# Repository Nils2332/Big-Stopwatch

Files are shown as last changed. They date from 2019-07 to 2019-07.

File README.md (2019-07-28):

# Big-3D-Printed-Stopwatch

A simple 4 digit stopwatch triggered by 2 remote Buttons

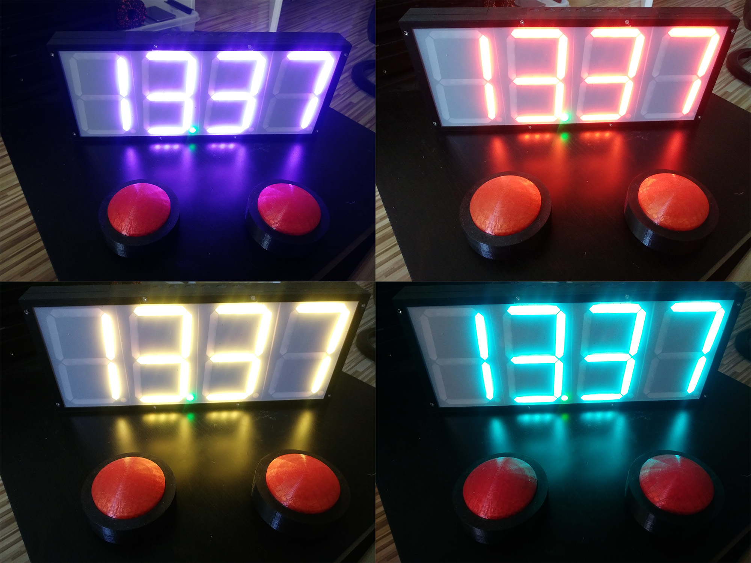
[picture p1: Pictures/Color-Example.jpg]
Overview

Overview
Main Body
Exploded Animation of the Main-Body
Animation Demo<br />
Demo of the running anmimation and rainbow highscore sign
## Built With
Counter powered by an ESP32 for future Extension with an Bluetooth App and more Functionalety.<br />
Programmeble WS2812 LEDs<br />
Remote Buttons: Custom PCB powered by an STM32F103<br />
Radio: nRF905 on 868 MHz band<br />

## License

This project is licensed under the MIT License

## Acknowledgments
* Inspiration @Jankae

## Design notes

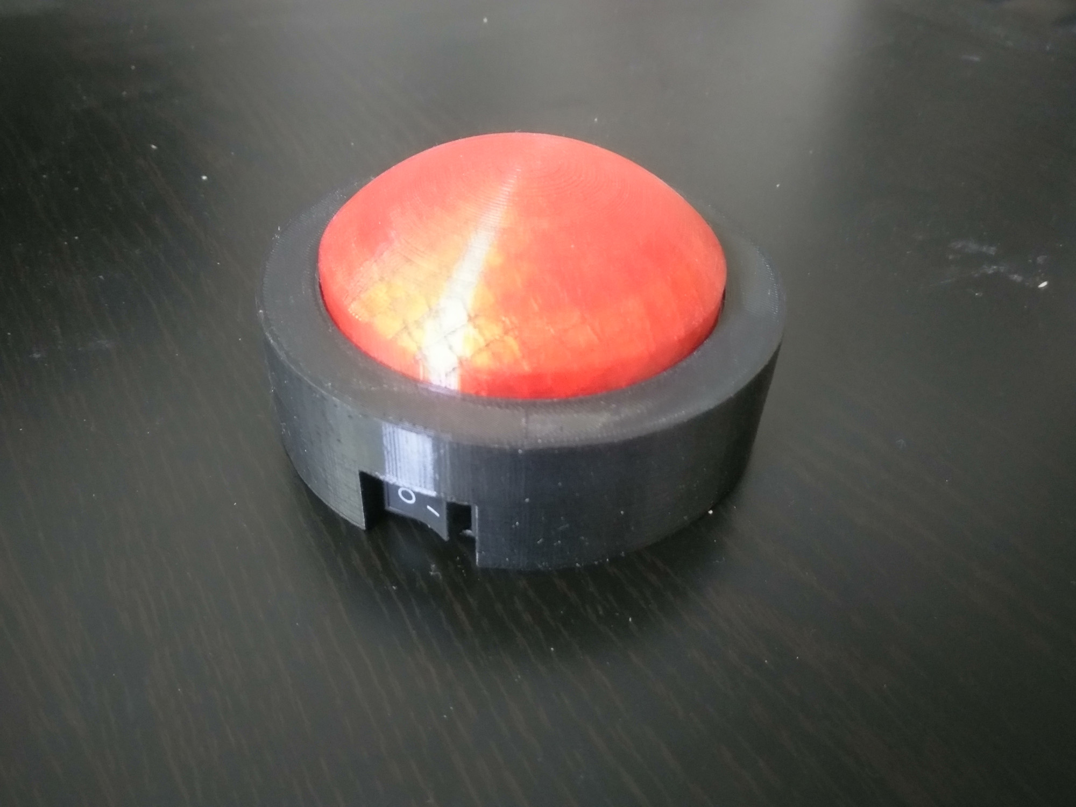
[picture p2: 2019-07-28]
Pictures/Button.jpg

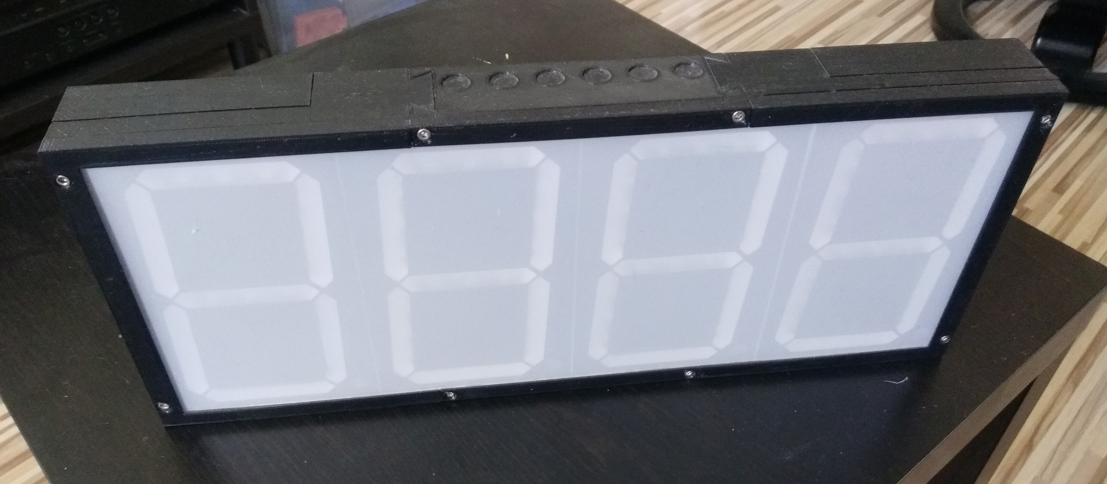
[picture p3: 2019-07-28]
Pictures/Main-Case.jpg

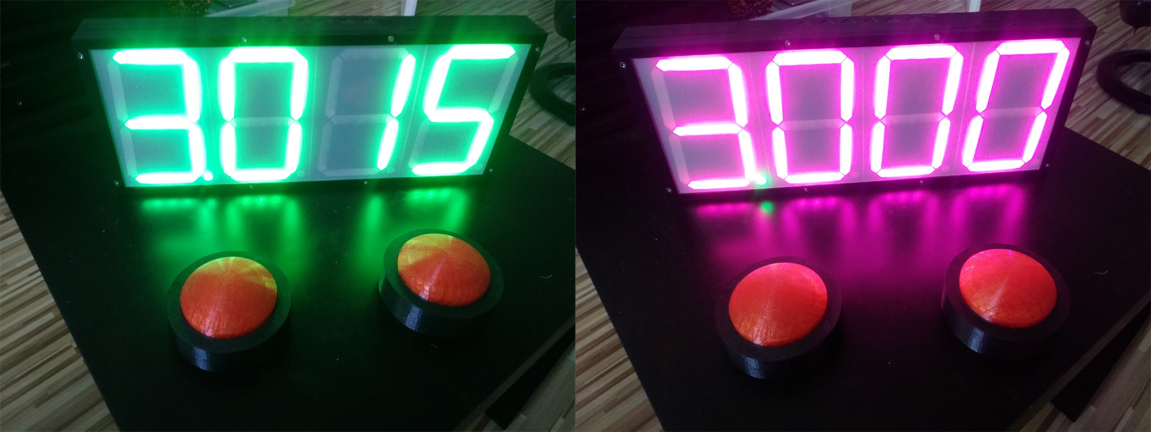
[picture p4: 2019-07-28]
Pictures/Button-Voltage.jpg

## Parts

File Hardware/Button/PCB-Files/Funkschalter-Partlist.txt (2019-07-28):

Partlist

Exported from Funkschalter1V0.1.sch at 01.06.2018 23:58

EAGLE Version 9.0.0 Copyright (c) 1988-2018 Autodesk, Inc.

Assembly variant: 

Part     Value             Device            Package     Library     Sheet

BAT1+    TPTP20R           TPTP20R           TP20R       testpad     1
BAT1-    TPTP20R           TPTP20R           TP20R       testpad     1
BAT2+    TPTP20R           TPTP20R           TP20R       testpad     1
BAT2-    TPTP20R           TPTP20R           TP20R       testpad     1
C1       0.1uF             C-EUC0603         C0603       rcl         1
C2       0.1uF             C-EUC0603         C0603       rcl         1
C3       10nF              C-EUC0603         C0603       rcl         1
C4       4,7uF             C-EUC0603         C0603       rcl         1
C6       4,7uF             C-EUC0603         C0603       rcl         1
C19      10nF              C-EUC0603         C0603       rcl         1
C20      4.7uF             C-EUC0603         C0603       rcl         1
C21      22pF              C-EUC0603         C0603       rcl         1
C22      22pF              C-EUC0603         C0603       rcl         1
C23      33pF              C-EUC0603         C0603       rcl         1
C24      3.3nF             C-EUC0603         C0603       rcl         1
C25      33pF              C-EUC0603         C0603       rcl         1
C26      33pF              C-EUC0603         C0603       rcl         1
C27      10nF              C-EUC0603         C0603       rcl         1
C28      33pF              C-EUC0603         C0603       rcl         1
C29      5.6pF             C-EUC0603         C0603       rcl         1
C30      4.7pF             C-EUC0603         C0603       rcl         1
C31      3.9pF             C-EUC0603         C0603       rcl         1
IC1      nRF905            NRF905QFN32_5X5MM QFN32-5X5MM nordic-semi 1
Q1       X322516MRB4SI     XTAL-4-3225       NX3225      adafruit    1
R1       10k               R-EU_R0603        R0603       rcl         1
R2       1M                R-EU_R0603        R0603       rcl         1
R3       22k               R-EU_R0603        R0603       rcl         1
R4       10k               R-EU_R0603        R0603       rcl         1
R5       0                 R-EU_R0603        R0603       rcl         1
R6       20k               R-EU_R0603        R0603       rcl         1
R7       100k              R-EU_R0603        R0603       rcl         1
R8       200k              R-EU_R0603        R0603       rcl         1
R9       18k               R-EU_R0603        R0603       rcl         1
R10      0                 R-EU_R0603        R0603       rcl         1
ST-LINK  B5B-ZR            B5B-ZR            B5B-ZR      jst         1
SW1      K2-6639SP-C4SC-04 SPST_TACT-EVQQ2   EVQ-Q2      adafruit    1
SW2      TS                SPST_TACT-EVQQ2   EVQ-Q2      adafruit    1
SW3      TS                SPST_TACT-EVQQ2   EVQ-Q2      adafruit    1
SW4      TS                SPST_TACT-EVQQ2   EVQ-Q2      adafruit    1
SW5      TS                SPST_TACT-EVQQ2   EVQ-Q2      adafruit    1
SW6      TS                SPST_TACT-EVQQ2   EVQ-Q2      adafruit    1
SW7      TS                SPST_TACT-EVQQ2   EVQ-Q2      adafruit    1
SW8      TS                SPST_TACT-EVQQ2   EVQ-Q2      adafruit    1
SW9      SPST_TACT-EVQQ2   SPST_TACT-EVQQ2   EVQ-Q2      adafruit    1
U$1      STM32F030F4       STM32F030F4       TSSOP20     stm32f030f4 1
UART     B4B-ZR            B4B-ZR            B4B-ZR      jst         1

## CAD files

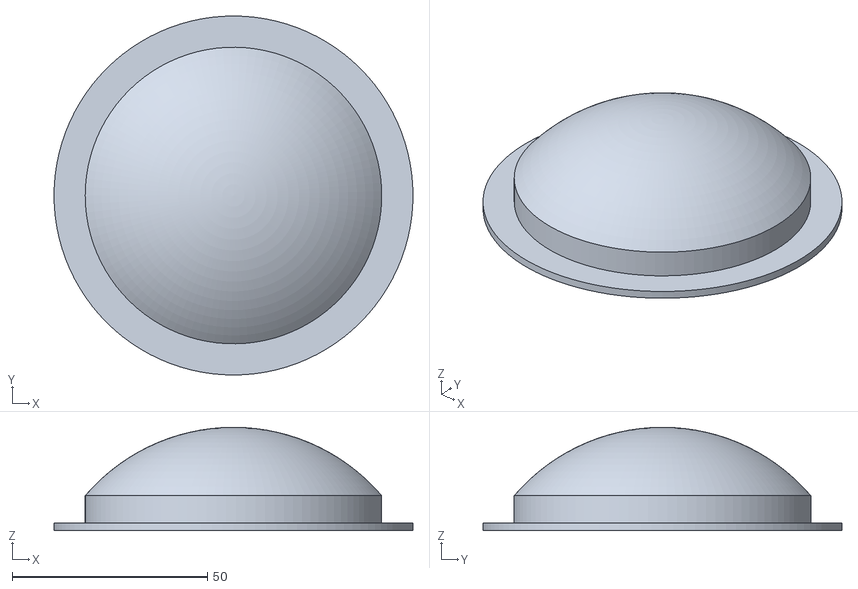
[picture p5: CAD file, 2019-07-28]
Hardware/Button/CAD-files/Bauteil2.stl
92.0 x 92.0 x 26.5

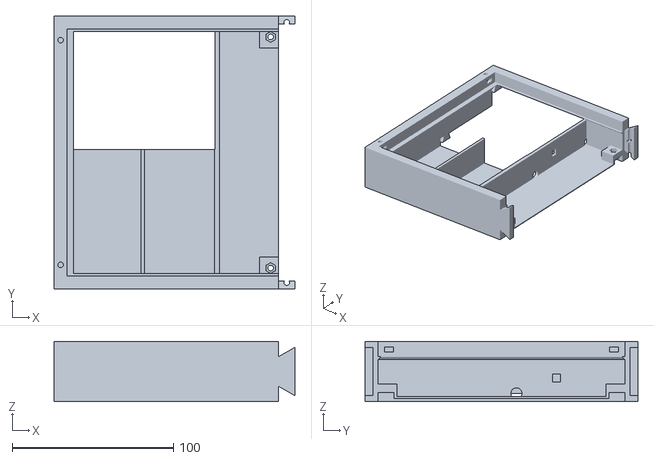
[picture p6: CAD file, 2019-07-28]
Hardware/Counter/CAD-files/Case_side_back.stl
149.4 x 169.5 x 37.3

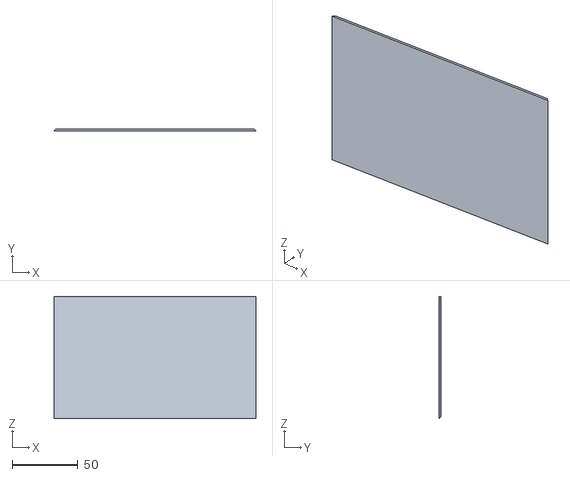
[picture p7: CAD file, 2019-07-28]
Hardware/Counter/CAD-files/Print/Zwischenplatt.stl
153.5 x 1.50 x 93.0

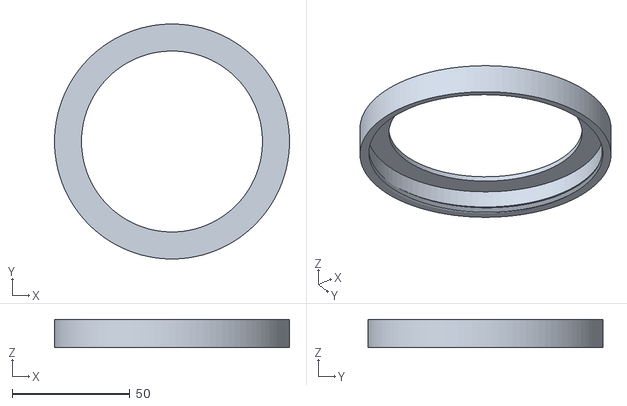
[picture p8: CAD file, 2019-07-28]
Hardware/Button/CAD-files/Bauteil5.stl
100.0 x 100.0 x 12.0

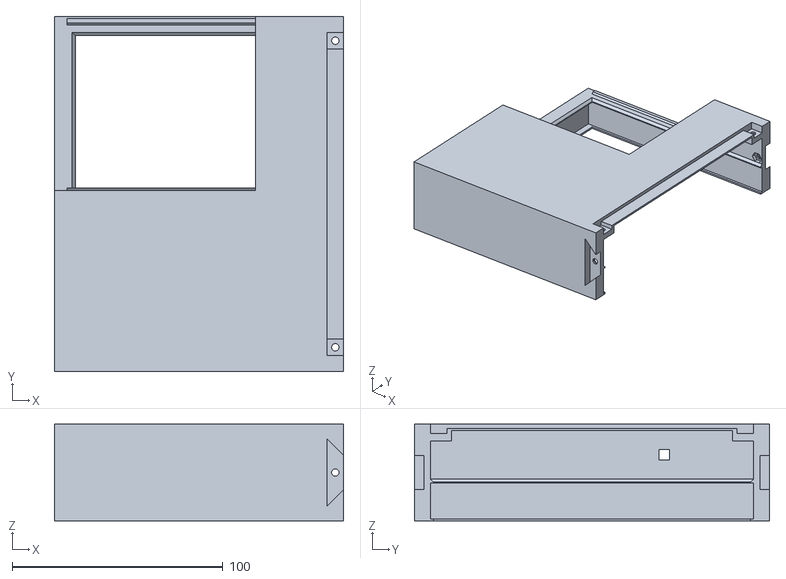
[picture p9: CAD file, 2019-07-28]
Hardware/Counter/CAD-files/Bauteil1_MIR.stl
137.4 x 168.5 x 46.0

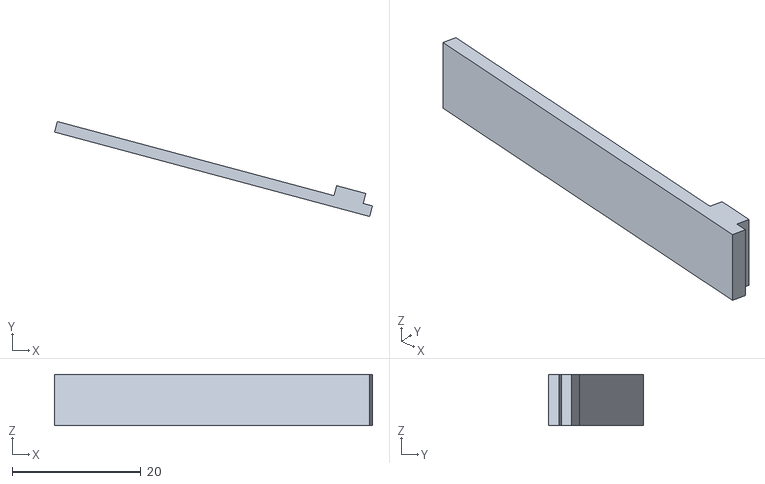
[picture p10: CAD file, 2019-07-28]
Hardware/Button/CAD-files/Spring.stl
49.4 x 14.8 x 8.00

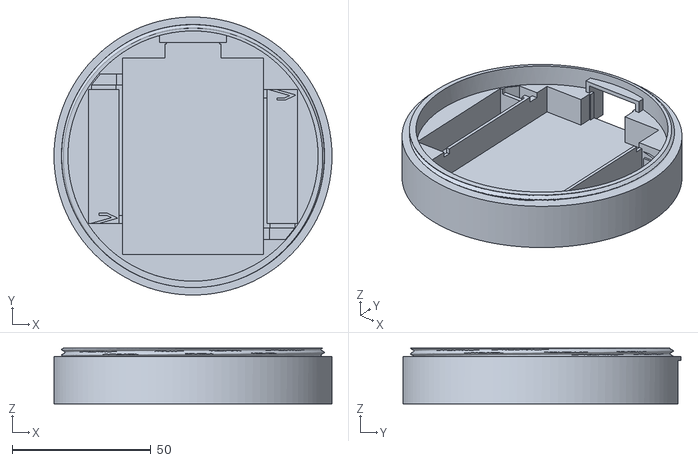
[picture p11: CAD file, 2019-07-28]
Hardware/Button/CAD-files/Bauteil6.stl
100.0 x 100.0 x 20.0

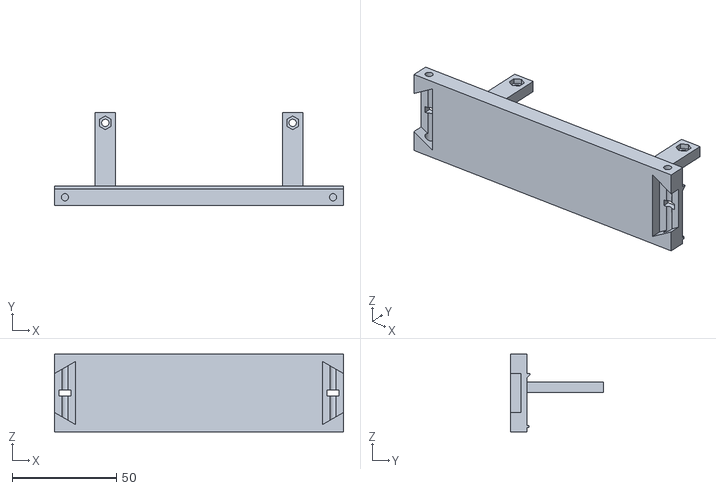
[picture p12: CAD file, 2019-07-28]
Hardware/Counter/CAD-files/Case_bottom_back.stl
138.8 x 44.7 x 37.3

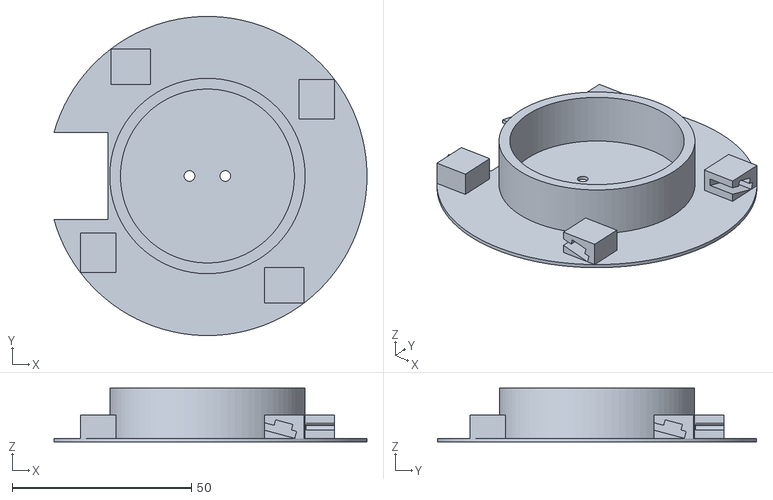
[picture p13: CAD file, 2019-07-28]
Hardware/Button/CAD-files/Bauteil1.stl
87.3 x 89.0 x 15.0

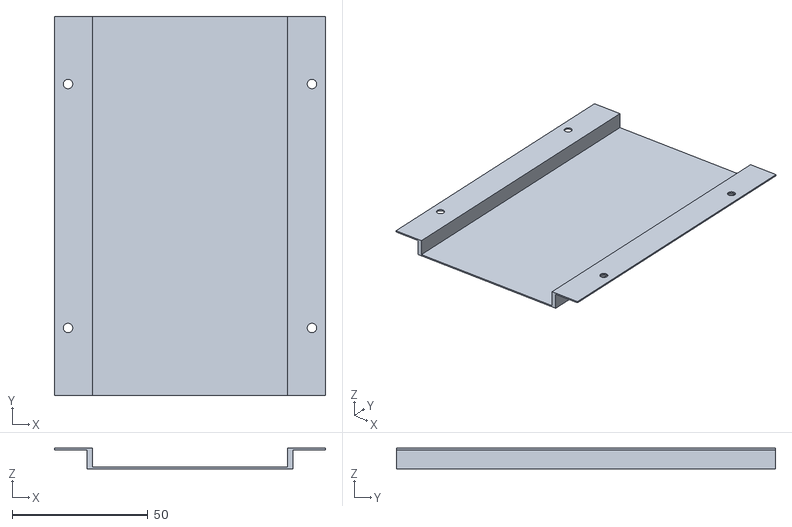
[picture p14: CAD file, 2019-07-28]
Hardware/Counter/CAD-files/PCB-Mount.stl
100.0 x 140.0 x 7.60

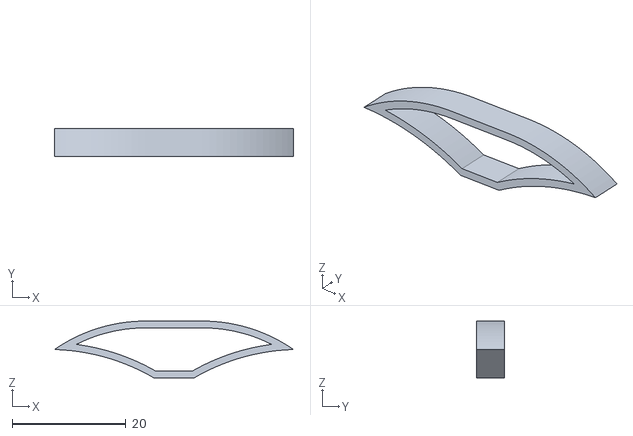
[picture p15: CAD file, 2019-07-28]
Hardware/Button/CAD-files/Spring2.stl
42.0 x 5.00 x 10.0

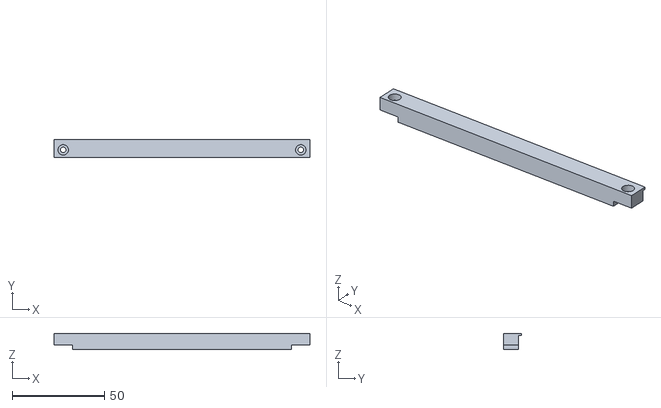
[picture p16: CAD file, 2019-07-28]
Hardware/Counter/CAD-files/Case_bottom_front.stl
138.8 x 9.50 x 8.90

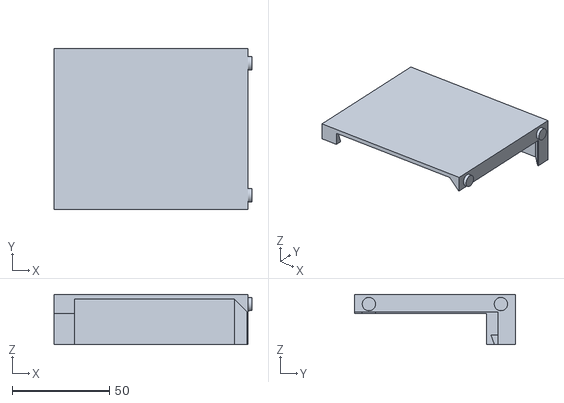
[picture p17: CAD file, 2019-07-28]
Hardware/Counter/CAD-files/Batcap3_MIR.stl
102.0 x 82.9 x 25.9

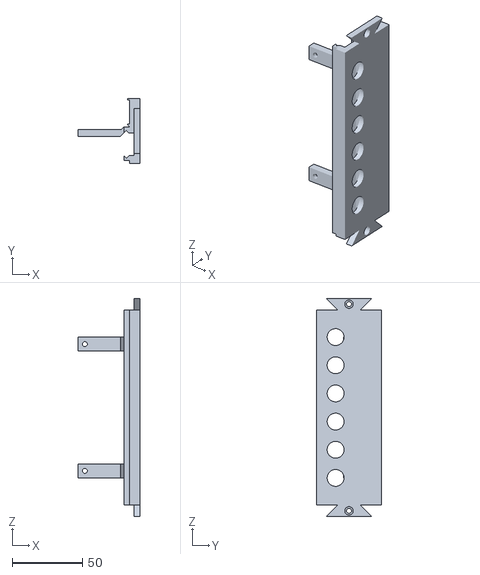
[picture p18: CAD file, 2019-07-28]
Hardware/Counter/CAD-files/TopFrame.stl
44.2 x 46.0 x 154.8

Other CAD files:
Hardware/Counter/CAD-files/Case_side_back_MIR1.stl
Hardware/Counter/CAD-files/Batcap3.stl
Hardware/Counter/CAD-files/Bauteil1.stl
Hardware/Counter/CAD-files/Cover_V2.stl
Hardware/Button/CAD-files/Bauteil1.ipt
Hardware/Button/CAD-files/Bauteil2.ipt
Hardware/Button/CAD-files/Bauteil5.ipt
Hardware/Button/CAD-files/Bauteil6.ipt
Hardware/Button/CAD-files/Button.iam
Hardware/Button/CAD-files/OldVersions/Bauteil1.0010.ipt
Hardware/Button/CAD-files/OldVersions/Bauteil2.0001.ipt
Hardware/Button/CAD-files/OldVersions/Bauteil5.0001.ipt
Hardware/Button/CAD-files/OldVersions/Bauteil6.0009.ipt
Hardware/Button/CAD-files/OldVersions/Button.0009.iam
Hardware/Button/CAD-files/OldVersions/Spring.0003.ipt
Hardware/Button/CAD-files/OldVersions/Spring2.0001.ipt
Hardware/Button/CAD-files/Spring.ipt
Hardware/Button/CAD-files/Spring2.ipt
Hardware/Counter/CAD-files/Backplate-housing.ipt
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

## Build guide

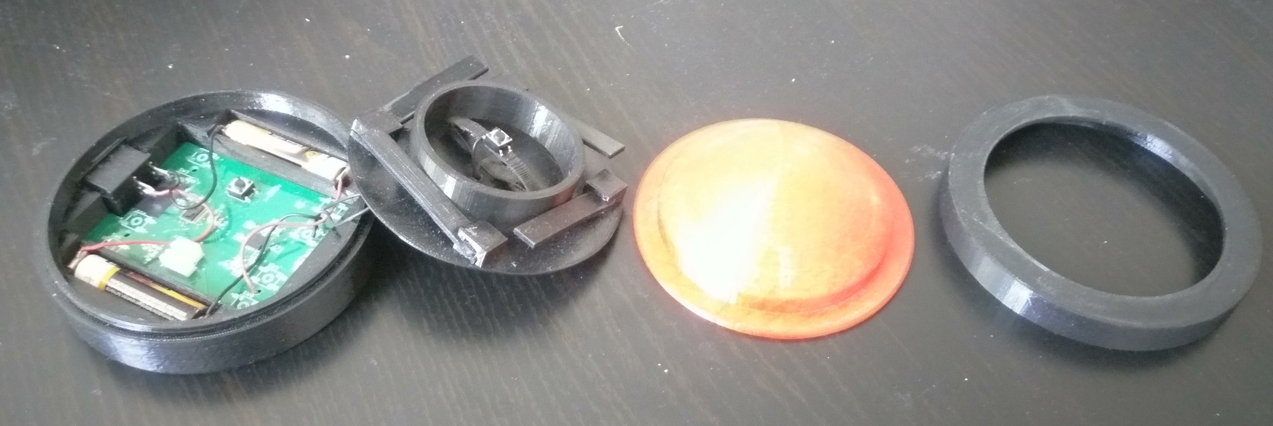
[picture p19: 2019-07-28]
Pictures/Button-disassembled.jpg

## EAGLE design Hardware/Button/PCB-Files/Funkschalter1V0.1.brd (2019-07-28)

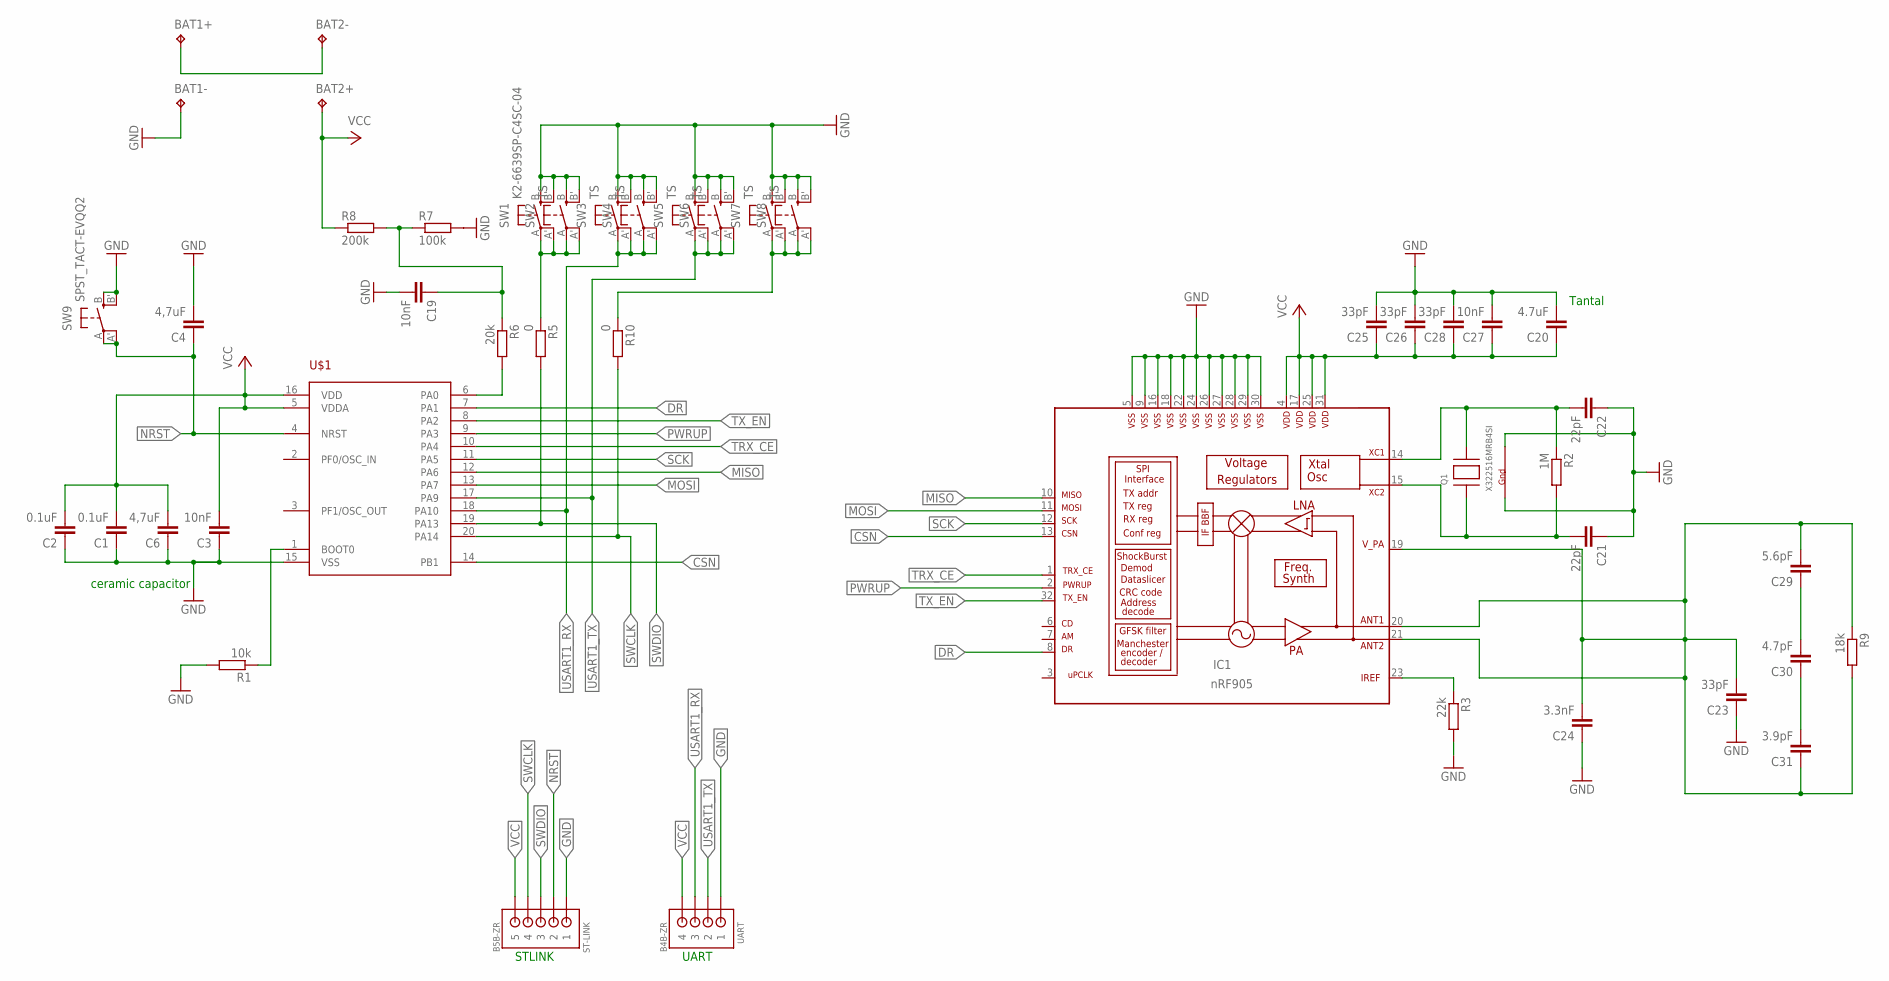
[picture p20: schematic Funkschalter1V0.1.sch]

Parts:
BAT1+, BAT1-, BAT2+, BAT2-: TPTP20R; TP20R
C1, C2: 0.1uF; C0603
C3, C19, C27: 10nF; C0603
C4, C6: 4,7uF; C0603
C20: 4.7uF; C0603
C21, C22: 22pF; C0603
C23, C25, C26, C28: 33pF; C0603
C24: 3.3nF; C0603
C29: 5.6pF; C0603
C30: 4.7pF; C0603
C31: 3.9pF; C0603
IC1: nRF905; QFN32-5X5MM
Q1: X322516MRB4SI; NX3225
R1: 10k; R0603
R2: 1M; R0603
R3: 22k; R0603
R5, R10: 0; R0603
R6: 20k; R0603
R7: 100k; R0603
R8: 200k; R0603
R9: 18k; R0603
ST-LINK: B5B-ZR
SW1: K2-6639SP-C4SC-04; EVQ-Q2
SW2, SW3, SW4, SW5, SW6, SW7, SW8: TS; EVQ-Q2
SW9: SPST_TACT-EVQQ2; EVQ-Q2
U$1: STM32F030F4; TSSOP20
UART: B4B-ZR

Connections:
CSN: IC1.13 (CSN), U$1.14 (PB1)
DR: IC1.8 (DR), U$1.7 (PA1)
GND: BAT1-.TP, C1.1, C2.1, C3.1, C4.2, C6.1, C19.2, C20.2, C21.1, C22.1, C23.1, C24.1, C25.2, C26.2, C27.2, C28.2, IC1.5 (VSS5), IC1.9 (VSS9), IC1.16 (VSS16), IC1.18 (VSS18), IC1.22 (VSS22), IC1.24 (VSS24), IC1.26 (VSS26), IC1.27 (VSS27), IC1.28 (VSS28), IC1.29 (VSS29), IC1.30 (VSS30), Q1.2 (G2), Q1.4 (G1), R1.2, R3.2, R7.2, ST-LINK.1, SW1.B (S), SW1.B' (S1), SW2.B (S), SW2.B' (S1), SW3.B (S), SW3.B' (S1), SW4.B (S), SW4.B' (S1), SW5.B (S), SW5.B' (S1), SW6.B (S), SW6.B' (S1), SW7.B (S), SW7.B' (S1), SW8.B (S), SW8.B' (S1), SW9.B (S), SW9.B' (S1), U$1.15 (VSS), UART.1
MISO: IC1.10 (MISO), U$1.12 (PA6)
MOSI: IC1.11 (MOSI), U$1.13 (PA7)
unnamed: R5.1, SW1.A, SW1.A' (P1), SW2.A, SW2.A' (P1)
unnamed: R1.1, U$1.1 (BOOT0)
unnamed: R6.2, U$1.6 (PA0)
unnamed: R10.1, SW7.A, SW7.A' (P1), SW8.A, SW8.A' (P1)
unnamed: BAT1+.TP, BAT2-.TP
unnamed: C19.1, R6.1, R7.1, R8.2
unnamed: C21.2, IC1.15 (XC2), Q1.1 (X1), R2.2
unnamed: C22.2, IC1.14 (XC1), Q1.3 (X2), R2.1
unnamed: IC1.23 (IREF), R3.1
unnamed: C23.2, C24.2, C29.2, C31.1, IC1.19 (VDD_PA), IC1.20 (ANT1), IC1.21 (ANT2), R9.1, R9.2
unnamed: C30.1, C31.2
unnamed: C29.1, C30.2
NRST: C4.1, ST-LINK.2, SW9.A, SW9.A' (P1), U$1.4 (NRST)
PWRUP: IC1.2 (PWR_UP), U$1.9 (PA3)
SCK: IC1.12 (SCK), U$1.11 (PA5)
SWCLK: R10.2, ST-LINK.4, U$1.20 (PA14)
SWDIO: R5.2, ST-LINK.3, U$1.19 (PA13)
TRX_CE: IC1.1 (TRX_CE), U$1.10 (PA4)
TX_EN: IC1.32 (TX_EN), U$1.8 (PA2)
USART1_RX: SW3.A, SW3.A' (P1), SW4.A, SW4.A' (P1), U$1.18 (PA10), UART.3
USART1_TX: SW5.A, SW5.A' (P1), SW6.A, SW6.A' (P1), U$1.17 (PA9), UART.2
VCC: BAT2+.TP, C1.2, C2.2, C3.2, C6.2, C20.1, C25.1, C26.1, C27.1, C28.1, IC1.4 (VDD4), IC1.17 (VDD17), IC1.25 (VDD25), IC1.31 (DVDD1V2), R8.1, ST-LINK.5, U$1.5 (VDDA), U$1.16 (VDD), UART.4

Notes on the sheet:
ceramic capacitor
Tantal
UART
STLINK

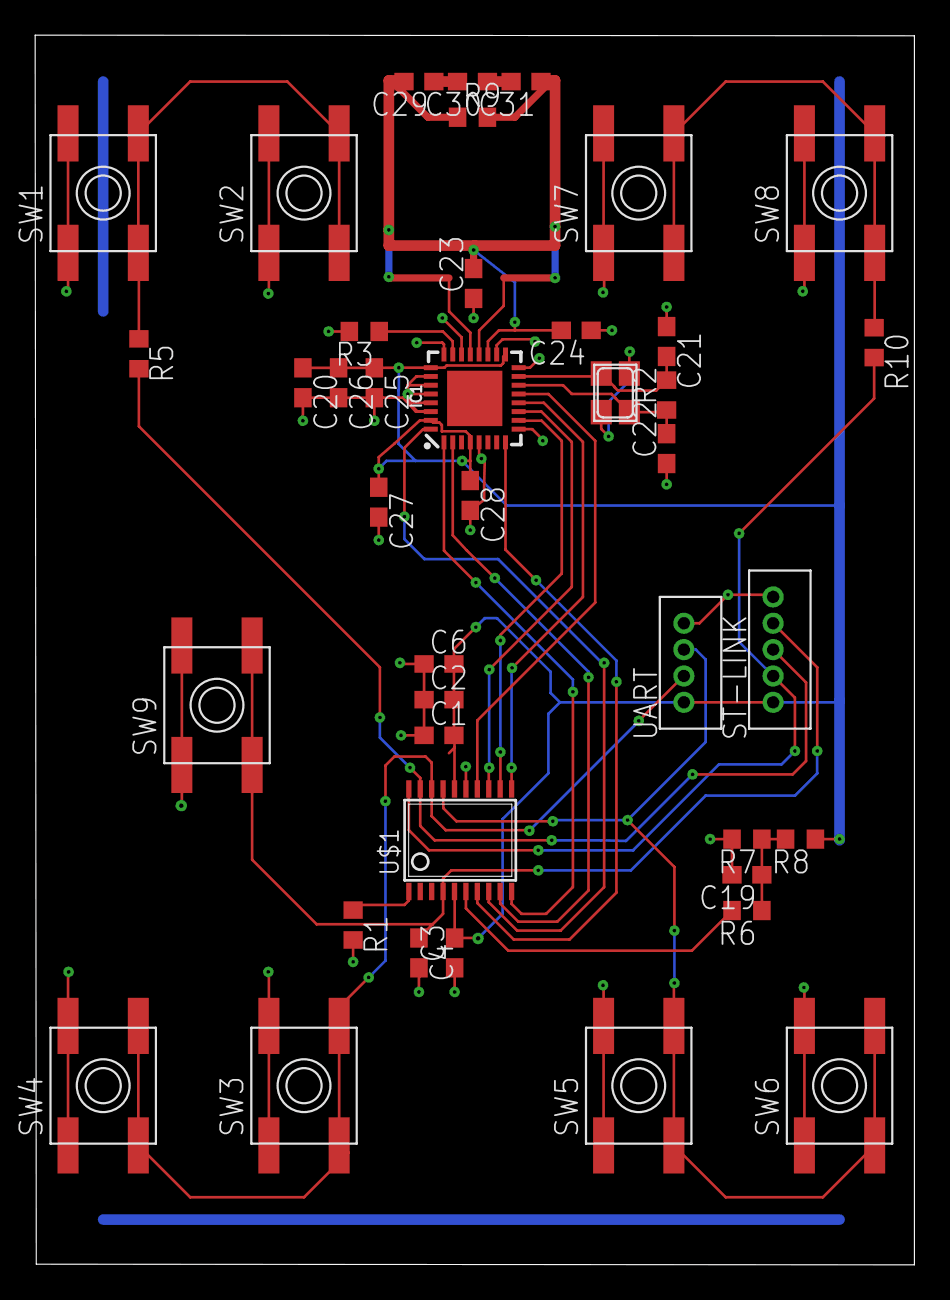
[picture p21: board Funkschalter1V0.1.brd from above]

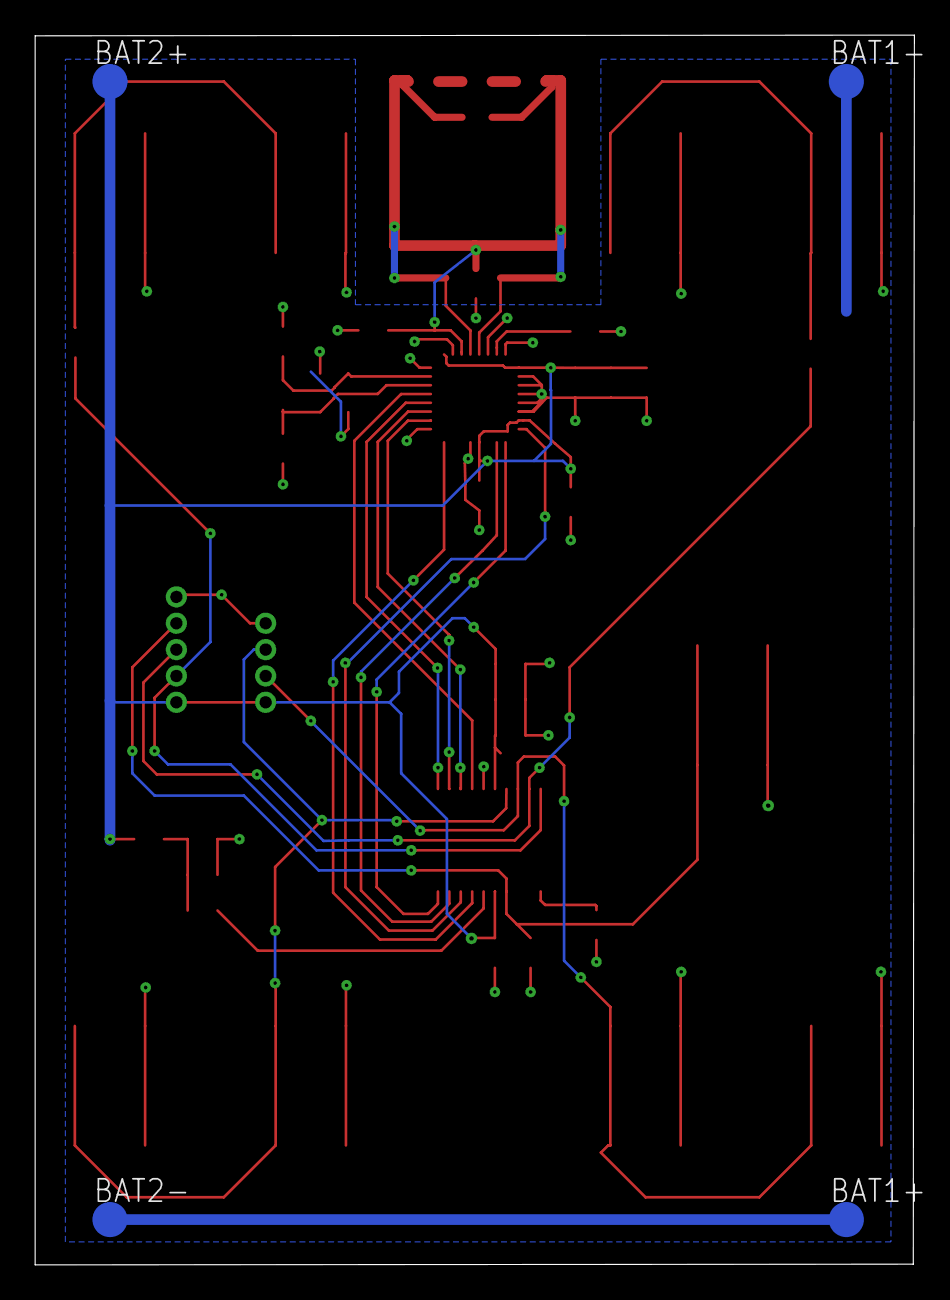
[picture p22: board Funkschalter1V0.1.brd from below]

Board: 2 copper layers, 50.0 x 70.0 mm, 45 parts (4 on the bottom side), 27 nets.

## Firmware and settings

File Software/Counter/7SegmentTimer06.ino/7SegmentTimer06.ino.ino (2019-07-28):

//Nils Schröder
//28.09.2018

#include <math.h>
#include <stdlib.h>
#include "nRF905\src\nRF905.h"
#include "LCD.h"
#include "modes.h"
#include "Debug.h"


#define T6 33
#define T5 25
#define T4 26
#define T3 27
#define T2 34
#define T1 35


#define RXADDR	0xABBAFFE0
#define TX1ADDR	0xABBAFFE1
#define TX2ADDR	0xABBAFFE2


#define Batpin1	4
#define Batpin2	2


uint8_t button[6] = { 0 };
uint8_t buttons = 0;
uint8_t button_used = 0;


double V_Bat1, V_Bat2;
double V_Button[2];

uint8_t V_Batlow = 0;
uint32_t oldtime_V = 0;

uint8_t remotereset = 0;
uint32_t remotedelay[2];
uint32_t remotecounter = 0;


LEDLCD LCD1(0);

float stattime;
float oldtime;
float record = 0;
uint8_t recordset = 0;

uint8_t remotebutton = 0;

uint8_t v_buttonshow = 0;

hw_timer_t * timer1 = NULL;
hw_timer_t * timer2 = NULL;
hw_timer_t * timer3 = NULL;

uint32_t oldtime_l = 0;
uint32_t sleepcounter = 0;
uint8_t sleeping = 0;

//timer1
void IRAM_ATTR getButtons()
{
	button[0] = !digitalRead(T1);
	button[1] = !digitalRead(T2);
	button[2] = !digitalRead(T3);
	button[3] = !digitalRead(T4);
	button[4] = !digitalRead(T5);
	button[5] = !digitalRead(T6);

	buttons = button[5] * 32 + button[4] * 16 + button[3] * 8 + button[2] * 4 + button[1] * 2 + button[0];

	button_used = 0;
	//Serial.println(buttons);
}


uint8_t oldpacket[2] = {};
//timer2
void IRAM_ATTR getRadio()
{

	remotecounter++;

	if (remotecounter > 350)
		remotereset = 0;
	//timerAlarmDisable(timer1);
	//timerAlarmDisable(timer2);
	//timerAlarmDisable(timer3);

	if (digitalRead(17))
	{
		Serial.print("Get Wireless: ");
		uint8_t buffer[NRF905_MAX_PAYLOAD];
		nRF905_read(buffer, sizeof(buffer));

		uint8_t id;
		uint8_t command;
		uint16_t timer;

		uint8_t packet;
		

		if (buffer[0] == 130)
		{
			id = buffer[1];
			command = buffer[2];
			packet = buffer[5];

			Serial.print(id);
			Serial.print("\t Packet: "), Serial.print(packet);
			//Voltage
			if (command == 1)
			{
				Serial.print("Voltage: ");
				V_Button[id - 1] = ((uint16_t)(buffer[3] << 8) | (buffer[4]));
				V_Button[id - 1] = V_Button[id - 1] / 1000;

				v_buttonshow = id;

				
				Serial.print("\t V: "), Serial.print(V_Button[id - 1]);

				oldpacket[id - 1] = packet;
			}
			//Button Pressed
			if (command == 2)
			{
				if (packet != oldpacket[id - 1])
				{

					timer = ((uint16_t)(buffer[3] << 8) | (buffer[4]));
					Serial.print("\t Delay: ");
					Serial.print(timer);
					remotedelay[id - 1] = timer;
					remotebutton = 1 << (id - 1);
					//Serial.println(buttons);
					button_used = 0;

					if (id == 1)
					{
						remotecounter = 0;
						remotereset++;
						Serial.print("\t Res#: "), Serial.print(remotereset);
					}

					oldpacket[id - 1] = packet;
				}
			}

			//ACK Packet
			//uint8_t compare[NRF905_MAX_PAYLOAD] = { 65, 67, 75, 0 };
			uint8_t compare[NRF905_MAX_PAYLOAD] = { 0 };
			compare[0] = 65;
			compare[1] = 67;
			compare[2] = 75;
			
			//for (uint8_t i = 0; i < NRF905_MAX_PAYLOAD; i++)
			//	Serial.print(compare[i]);

			//Serial.println(" ");

			if (id == 1)
			{
				Serial.println("\t Sending ACK");
				//Serial.println(id);
				while (!nRF905_TX(TX1ADDR, compare, sizeof(buffer), NRF905_NEXTMODE_RX));
			}

			if (id == 2)
			{
				Serial.println("\t Sending ACK");
				//Serial.println(id);
				while (!nRF905_TX(TX2ADDR, compare, sizeof(buffer), NRF905_NEXTMODE_RX));
			}
		}
	}

	//timerAlarmEnable(timer1);
	//timerAlarmEnable(timer2);
	//timerAlarmEnable(timer3);
}

//timer3
void IRAM_ATTR updateDisplay()
{
	//timerAlarmDisable(timer1);
	//timerAlarmDisable(timer2);
	//timerAlarmDisable(timer3);

	

	//timerAlarmEnable(timer1);
	//timerAlarmEnable(timer2);
	//timerAlarmEnable(timer3);
}

void setup()
{
	analogSetAttenuation(ADC_6db);

	//init Serial
	Serial.begin(115200);

	//configure Buttons
	pinMode(T1, INPUT);
	pinMode(T2, INPUT);
	pinMode(T3, INPUT);
	pinMode(T4, INPUT);
	pinMode(T5, INPUT);
	pinMode(T6, INPUT);

	digitalWrite(T1, HIGH);
	digitalWrite(T2, HIGH);
	digitalWrite(T3, HIGH);
	digitalWrite(T4, HIGH);
	digitalWrite(T5, HIGH);
	digitalWrite(T6, HIGH);
	//end Buttons

	//radio Avaiable PIN
	pinMode(17, INPUT);

	// Start up radio
	nRF905_init();

	// Set address of this device
	nRF905_setListenAddress(RXADDR);

	// Put into receive mode
	nRF905_RX();
	nRF905_powerUp();
	nRF905_RX();


	LCD1.init();

	//Timer init
	//esp_task_wdt_fee

	timer1 = timerBegin(1, 80, true);
	timerAttachInterrupt(timer1, &getButtons, true);
	timerAlarmWrite(timer1, 5000, true);
	timerAlarmEnable(timer1);

	timer2 = timerBegin(2, 80, true);
	timerAttachInterrupt(timer2, &getRadio, true);
	timerAlarmWrite(timer2, 5000, true);
	timerAlarmEnable(timer2);

	timer3 = timerBegin(0, 80, true);
	timerAttachInterrupt(timer3, &updateDisplay, true);
	timerAlarmWrite(timer3, 10000, true);
	timerAlarmEnable(timer3);

	//End timer


	Serial.println("7-Segment-Counter-Start");

	LCD1.setcolorhsv(0, 240, 1, 1);
	LCD1.setcolorhsv(1, 120, 1, 1);

	LCD1.clearALL();

	uint8_t samples = 10;
	V_Bat1 = 0, V_Bat2 = 0;
	for (uint8_t i = 0; i < samples; i++)
	{
		V_Bat1 = V_Bat1 + analogRead(Batpin1);
		V_Bat2 = V_Bat2 + analogRead(Batpin2);
	}

	V_Bat1 = V_Bat1 / samples;
	V_Bat2 = V_Bat2 / samples;

	Serial.print("V1: \t");
	Serial.println(V_Bat1);
	Serial.print("V2: \t");
	Serial.println(V_Bat2);

	V_Bat1 = V_Bat1 * 0.0016414;
	V_Bat2 = V_Bat2 * 0.0027313 - V_Bat1;

	LCD1.show(V_Bat1);
	update();
	delay(2000);
	LCD1.show(V_Bat2);
	update();
	//delay(2000);

}

float starttime;
float time;

void v_showbutton()
{
	cHSV oldcolor;
	oldcolor = LCD1.hsv[0];
	if (v_buttonshow == 1)LCD1.setcolorhsv(0, 110, 1, 1);
	if (v_buttonshow == 2)LCD1.setcolorhsv(0, 350, 1, 1);
	LCD1.show(V_Button[v_buttonshow - 1]);
	update();
	delay(2000);
	LCD1.clearALL();
	update();
	LCD1.setcolorhsv(0, oldcolor.H, oldcolor.S, oldcolor.V);
	v_buttonshow = 0;
}

void update()
{
	timerAlarmDisable(timer1);
	timerAlarmDisable(timer2);
	timerAlarmDisable(timer3);

	LCD1.update();
	LCD1.writeLEDs();
	sleepcounter++;

	timerAlarmEnable(timer1);
	timerAlarmEnable(timer2);
	timerAlarmEnable(timer3);
}

void checkbat()
{
	uint8_t samples = 10;
	V_Bat1 = 0, V_Bat2 = 0;
	for (uint8_t i = 0; i < samples; i++)
	{
		V_Bat1 = V_Bat1 + analogRead(Batpin1);
		V_Bat2 = V_Bat2 + analogRead(Batpin2);
	}
	V_Bat1 = V_Bat1 / samples;
	V_Bat2 = V_Bat2 / samples;

	V_Bat1 = V_Bat1 * 0.0016414;
	V_Bat2 = V_Bat2 * 0.0027313 - V_Bat1;

	Serial.print("V1: \t");
	Serial.print(V_Bat1);
	Serial.print("\t\tV2: \t");
	Serial.println(V_Bat2);

	float lowbat = 3.2;

	if ((V_Bat1 < lowbat) || (V_Bat2 < lowbat))
	{
		V_Batlow = 1;
		LCD1.setcolorhsv(0, 0, 1, 5);
		LCD1.show(min(V_Bat1, V_Bat2));
		sleepcounter = 0;
		sleeping = 0;
	}
}
void loop()
{
	if (!V_Batlow)
	{
		if (millis() - oldtime_V > 10000)
			oldtime_V = millis(), checkbat();// Serial.println("up");

		if (v_buttonshow)
			v_showbutton();

		if(LCD1.animation!=4)
			mode1();
	}

	if ((sleepcounter > 300 && !sleeping) && !LCD1.animation)
		LCD1.fadeout(1, 1), sleeping = 1;

	if (millis() - oldtime_l > 10)
		oldtime_l = millis(), update();// Serial.println("up");

}

void mode0()
{

}

uint8_t m1_mode = 0;
float m1_break_start;
float m1_break_stop;
float m1_break = 0;
float endtime = 0;

void mode1()
{
	if (remotereset >= 3)
	{
		m1_mode = 0;
		LCD1.setZero();
		delay(300);
		remotebutton = 0;
	}

	if (recordset)
	{
		if (!LCD1.animation)
			recordset = 0, LCD1.colorWheel(1,2,0);
	}

	//Start
	if ((buttons == 1 && !button_used) || remotebutton == 1)
	{
		sleeping = 0;
		remotebutton = 0;

		if (m1_mode == 0)
		{
			starttime = (float)(millis() - remotedelay[0]) / 1000;
			LCD1.setZero();
			m1_break = 0;
		}
		button_used = 1;
		m1_mode = 1;

		oldtime = 0;
	}

	//Stop
	if (((buttons == 2 && !button_used) || remotebutton == 2) && m1_mode == 1)
	{
		sleeping = 0;
		remotebutton = 0;
		button_used = 1;
		m1_mode = 0;
		endtime = (float)(millis()-remotedelay[1]) / 1000 - starttime;
		//time = time - (remotedelay[1] / 1000);
		LCD1.anishow(endtime, 1, 1);

		if (record == 0 || endtime < record)
			recordset = 1, record = endtime;
		
		//oldtime = 0;
	}

	//Reset
	if (buttons == 4 && !button_used)
	{
		sleeping = 0;
		starttime = millis() / 1000;
		button_used = 1;
		m1_mode = 0;
		LCD1.setZero();
		oldtime = 0;
	}

	if (buttons == 8 && !button_used)
	{
		if (record != 0)
			record = 0;
	}

	//stop
	if (m1_mode == 0)
	{

	}

	//run
	if (m1_mode == 1)
	{
		sleepcounter = 0;

		time = (float)millis() / 1000 - starttime;
		if ((time - oldtime) >= 0.01)
		{
			//Serial.println(time);
			LCD1.anishowcontinuous(time, 1, 2);
			oldtime = time;
		}
	}

	if (buttons == 32 && !button_used)
	{
		button_used = 1;
		LCD1.setcolorhsv(0, LCD1.hsv[0].H + 30, LCD1.hsv[0].S, LCD1.hsv[0].V);
		Serial.print("newHue: "), Serial.println(LCD1.hsv[0].H);
		delay(300);
		sleepcounter = 0;
		sleeping = 0;
		LCD1.show(13.37);
	}
}

void mode2()
{

}

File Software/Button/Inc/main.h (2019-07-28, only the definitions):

#define DR_Pin GPIO_PIN_1
#define DR_GPIO_Port GPIOA
#define TX_EN_Pin GPIO_PIN_2
#define TX_EN_GPIO_Port GPIOA
#define PWRUP_Pin GPIO_PIN_3
#define PWRUP_GPIO_Port GPIOA
#define TRX_CE_Pin GPIO_PIN_4
#define TRX_CE_GPIO_Port GPIOA
#define CSN_Pin GPIO_PIN_1
#define CSN_GPIO_Port GPIOB
#define Button1_Pin GPIO_PIN_13
#define Button1_GPIO_Port GPIOA
#define Button1_EXTI_IRQn EXTI4_15_IRQn
#define Button2_Pin GPIO_PIN_14
#define Button2_GPIO_Port GPIOA
#define Button2_EXTI_IRQn EXTI4_15_IRQn

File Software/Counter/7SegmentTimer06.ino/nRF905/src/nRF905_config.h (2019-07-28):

/*
 * Project: nRF905 AVR/Arduino Library/Driver
 * Author: Zak Kemble, contact@zakkemble.co.uk
 * Copyright: (C) 2017 by Zak Kemble
 * License: GNU GPL v3 (see License.txt)
 * Web: http://blog.zakkemble.co.uk/nrf905-avrarduino-librarydriver/
 */

#ifndef NRF905_CONFIG_H_
#define NRF905_CONFIG_H_

// Crystal frequency (the one the radio module is using)
// NRF905_CLK_4MHZ
// NRF905_CLK_8MHZ
// NRF905_CLK_12MHZ
// NRF905_CLK_16MHZ
// NRF905_CLK_20MHZ
#define NRF905_CLK_FREQ		NRF905_CLK_16MHZ

// Use pin interrupt for data ready (DR)
// NOTE: If you have other devices connected that use the SPI bus then you will need to wrap those bits of code in NRF905_NO_INTERRUPT() blocks
#define NRF905_INTERRUPTS	0

// If you want to use the NRF905_CB_ADDRMATCH and NRF905_CB_RXINVALID callbacks with interrupts then both NRF905_INTERRUPTS and NRF905_INTERRUPTS_AM need to be enabled
#define NRF905_INTERRUPTS_AM	0

// If other libraries communicate with SPI devices while inside an interrupt then set this to 1, otherwise you can set this to 0
// If you're not sure then leave this at 1
// If this is 1 then global interrupts will be turned off when this library uses the SPI bus
#define NRF905_INT_SPI_COMMS	1

// Use software to get data ready state instead of reading pin for high/low state, this means you don't need to connect to DR pin
// This option can only be used if NRF905_INTERRUPTS is 0
#define NRF905_DR_SW		1

// Use software to get address match state instead of reading pin for high/low state, this means you don't need to connect to AM pin
// This option can only be used if NRF905_INTERRUPTS_AM is 0
#define NRF905_AM_SW		1

// Don't transmit if airway is busy (other transmissions are going on)
// This feature uses the CD pin
#define NRF905_COLLISION_AVOID	0


///////////////////
// Default radio settings
///////////////////

// Frequency
// Channel 0 is 422.4MHz for the 433MHz band, each channel increments the frequency by 100KHz, so channel 10 would be 423.4MHz
// Channel 0 is 844.8MHz for the 868/915MHz band, each channel increments the frequency by 200KHz, so channel 10 would be 846.8MHz
// Max channel is 511 (473.5MHz / 947.0MHz)
#define NRF905_CHANNEL			115

// Frequency band
// 868 and 915 are actually the same thing
// NRF905_BAND_433
// NRF905_BAND_868
// NRF905_BAND_915
#define NRF905_BAND			NRF905_BAND_868
// Output power
// n means negative, n10 = -10
// NRF905_PWR_n10 (-10dBm = 100uW)
// NRF905_PWR_n2 (-2dBm = 631uW)
// NRF905_PWR_6 (6dBm = 4mW)
// NRF905_PWR_10 (10dBm = 10mW)
#define NRF905_PWR			NRF905_PWR_10

// Save a few mA by reducing receive sensitivity
// NRF905_LOW_RX_DISABLE (Normal sensitivity)
// NRF905_LOW_RX_ENABLE (Lower sensitivity)
#define NRF905_LOW_RX		NRF905_LOW_RX_DISABLE

// Constantly retransmit payload while in transmit mode
// Can be useful in areas with lots of interference, but you'll need to make sure you can differentiate between re-transmitted packets and new packets (like an ID number).
// It will also block other transmissions if collision avoidance is enabled.
// NRF905_AUTO_RETRAN_DISABLE
// NRF905_AUTO_RETRAN_ENABLE
#define NRF905_AUTO_RETRAN	NRF905_AUTO_RETRAN_DISABLE

// Output a clock signal on pin 3 of IC
// NRF905_OUTCLK_DISABLE
// NRF905_OUTCLK_500KHZ
// NRF905_OUTCLK_1MHZ
// NRF905_OUTCLK_2MHZ
// NRF905_OUTCLK_4MHZ
#define NRF905_OUTCLK		NRF905_OUTCLK_DISABLE

// CRC checksum
// NRF905_CRC_DISABLE
// NRF905_CRC_8
// NRF905_CRC_16
#define NRF905_CRC			NRF905_CRC_16

// Address size
// The address is actually the SYNC part of the packet, just after the preamble and before the data
// NRF905_ADDR_SIZE_1 (not recommended, a lot of false invalid packets will be received)
// NRF905_ADDR_SIZE_4
#define NRF905_ADDR_SIZE	NRF905_ADDR_SIZE_4

// Payload size (1 - 32)
#define NRF905_PAYLOAD_SIZE	8 //NRF905_MAX_PAYLOAD


///////////////////
// Pin stuff
///////////////////

// Arduino pin assignments
#define NRF905_TRX_EN	21	// Enable/standby pin (Required)
#define NRF905_PWR_MODE	5	// Power mode pin (Required)
#define NRF905_TX_EN	22	// TX / RX mode pin (Required)
#define NRF905_CD		4	// Carrier detect pin (Optional, used for collision avoidance if NRF905_COLLISION_AVOID is 1 or if you want to use the nRF905_airwayBusy() function)
#define NRF905_CSN		16	// SPI slave select pin (Required)

// Data ready pin
// If using interrupts (NRF905_INTERRUPTS 1) then this must be an interrupt pin
// If NRF905_INTERRUPTS is 0 and NRF905_DR_SW is 1 then this pin does not need to be connected
#define NRF905_DR	17

// Address match pin
// If using AM interrupt (NRF905_INTERRUPTS_AM 1) then this must be an interrupt pin
// If NRF905_INTERRUPT_AM is 0 and NRF905_AM_SW is 1 then this pin does not need to be connected
#define NRF905_AM			2






// --------------------------------------
// Everything below here is for non-Arduino stuff
// --------------------------------------

// Enable/standby pin
#define NRF905_TRX_EN_PORT		D
#define NRF905_TRX_EN_BIT		7
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

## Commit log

2018-10-01 GITIGNORE und GITATTRIBUTES hinzufügen.
2018-10-02 Fixing tolerances
    [Bauteil1.0007.ipt, Bauteil1.0008.ipt, Bauteil1.ipt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]
2018-10-03 working LEDLCD
2018-10-04 adc update
2019-07-28 Add PCB Button,
    Button Code,
    Rearrange
    [Backplate-housing.0006.ipt, Backplate-housing.ipt, Backplate-housing.stl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]
2019-07-28 Move old_a files into subdir
    [Backplate-housing.0006.ipt, Backplate-housing.ipt, Backplate-housing.stl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]

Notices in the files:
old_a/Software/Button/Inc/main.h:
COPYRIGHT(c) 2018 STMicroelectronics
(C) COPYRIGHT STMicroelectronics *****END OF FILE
